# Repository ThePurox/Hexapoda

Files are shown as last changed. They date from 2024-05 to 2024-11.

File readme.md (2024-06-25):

# Hexapoda
The Hexapoda is a [hummingbird](https://github.com/PJE66/hummingbird) style 30 key keyboard designed around [hexagonal keycaps](https://hw.s-ol.nu/HEX-keycaps/), which require Choc v1 switches.
It uses the CH552T controller and [FAK firmware](https://github.com/semickolon/fak).
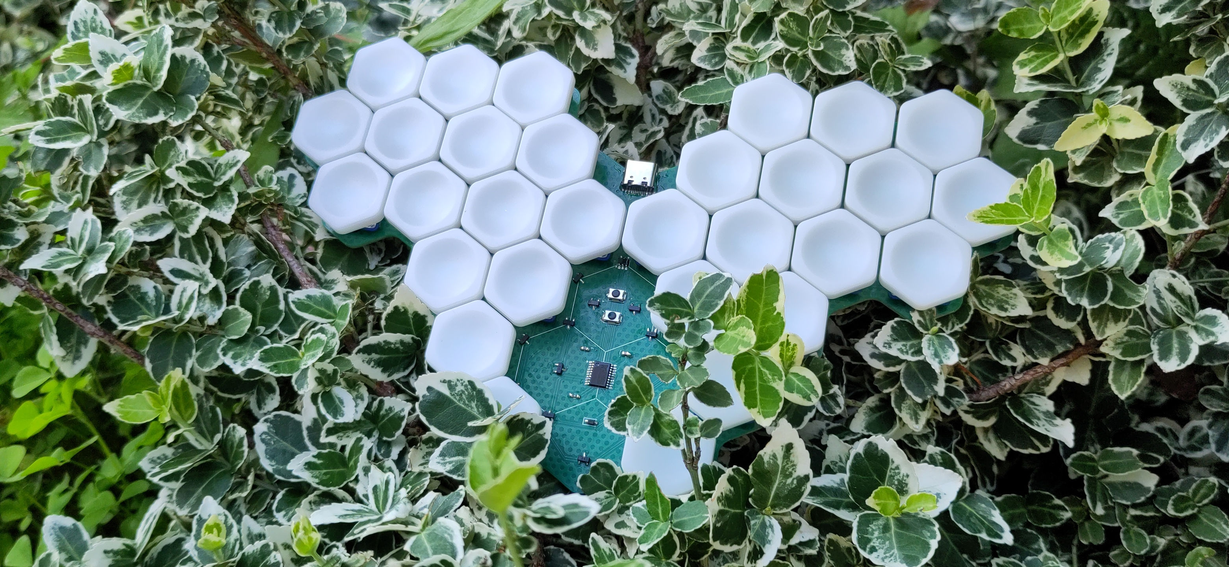
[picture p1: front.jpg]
front view of keyboard

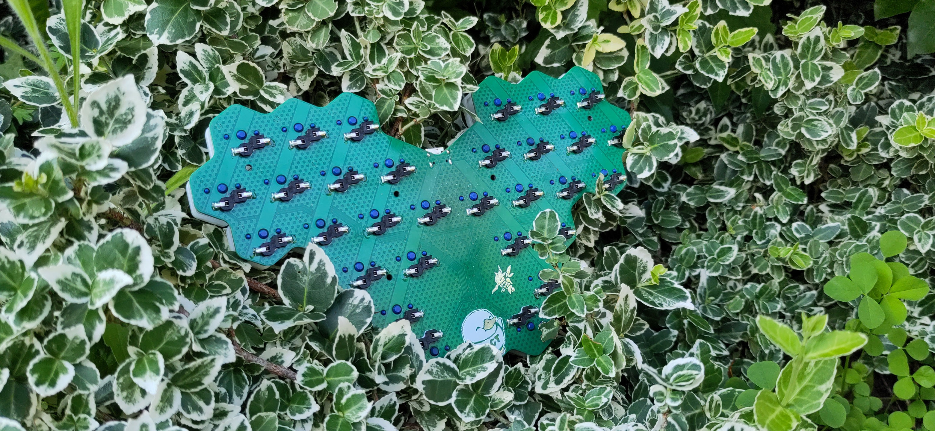
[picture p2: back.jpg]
back view of keyboard


The electronic design is inspired by the [MIAO MCU board](https://github.com/kilipan/miao).

# Buildguide
Soldering should be straight forward with the help of the [interactive bill of materials](bom/ibom.html)
The orientation of `U1` and `U2` are indicated by small arrows on the PCB.
The orientaion `D16` is such that its white line is on the side where the footprint on the silkscreen also has a white line.
For all other components, the orientation does not matter, or their form-factor allows only one orientation (`D1-D15`).
Make sure to also solder the metal legs on the side, as they will give stability to the jack.
Do **not** plug in a USB-cabel without soldering the metal legs on the side of the USB-jack! You will most likely rip off the USB-jack when unplugging the USB-cable!

# Flashing firmware
This keyboard is designed for the [FAK-firmware](https://github.com/semickolon/fak).
I've provided some example configuration files in [my fork](https://github.com/ThePurox/fak-config) of the fak-config repository with the keyboard name `hexapoda`.
The push-button closer to the USB-jack is the `BOOT` button. The one closer to the thumb keys is the `RESET` button.

# BOM
| Part | LCSC-Part Nr | amount |
|---|---|---|
| USB-C | C2765186 | 1 |
| CH552T | C111367 | 1 |
| BAV70 Diodes | C727123 | 15 |
| USBLC6-2SC6 | C6807798 | 1 |
| PMEG2010EA | C193668 | 1 |
| Push buttons | C115357 | 2 |
| Fuse | C311055 | 1 |
| 5.1k-Resistor | C23186 | 2 |
| 10k-Resistor | C25804 | 1 |
| 1uF-Capacitor | C2991434 | 2 |
| Hot-Swap-Sockets | | 30 |
| Choc V1 Switches | | 30 |

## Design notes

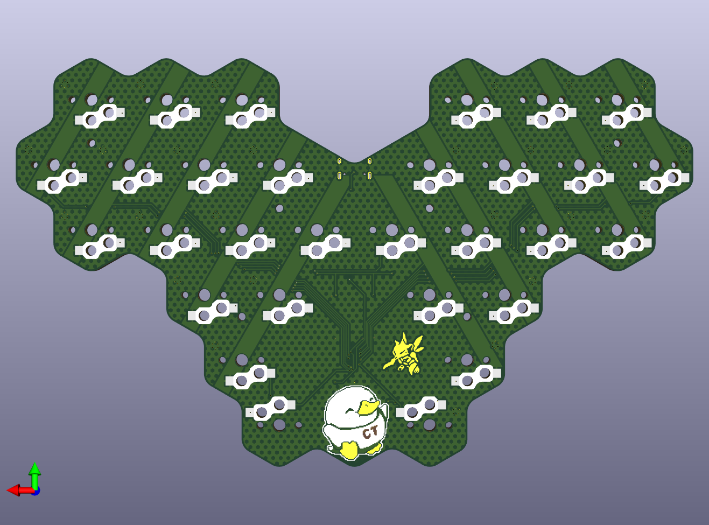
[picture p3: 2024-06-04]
back-pcb.png

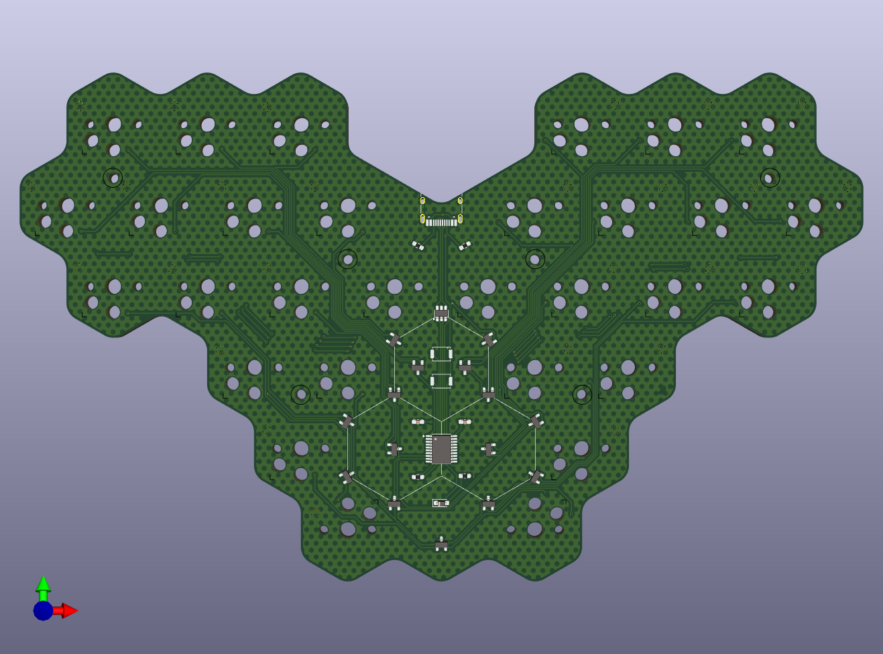
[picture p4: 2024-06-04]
front-pcb.png

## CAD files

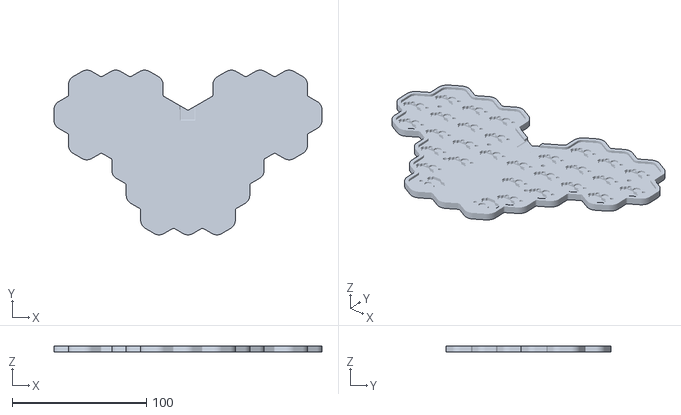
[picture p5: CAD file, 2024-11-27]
case/case.stl
199.5 x 122.6 x 4.40

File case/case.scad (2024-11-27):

$fn=20;

//hotswap
cyl_h=3.05;
cyl_d=3;

base_x=4.75;
base_x_sum=9.55;
base_y=4.65;
base_y_sum=6.85;
base_z=1.8;

clip_x=1.68;
clip_y=(13.15-9.95)/2;
clip_z=1.85;

// based on https://keycapsss.com/media/image/12/7a/49/kailh-choc-switch-low-profile-dimensions.png
// and on https://www.kailhswitch.com/Content/upload/2019306614/201911041105555019799.jpg
module choc_hs(){
    base_x = 4.75;
    base_y = 4.69;
    base_z=1.86;
    clip_x = 1.6;
    clip_y = 1.73;
    pin_h = 2.65;
    minkowski(){
        cylinder(h=0.8,d=1.5);
    rotate([180,0,0])translate([-9.75+base_x/2,-6.9+base_y/2,0]) // center around corner
    union(){
    translate([-base_x/2,-base_y/2,0]) // center around pin hole
    union(){ // HS
    cube([base_x,base_y,base_z]);
    translate([5,2.2,0])cube([base_x,base_y,base_z]);
    translate([base_x,0,0])rotate([0,0,45])cube([base_x+0.30,base_y,base_z]);

    translate([-clip_x,base_y/2-clip_y/2,0])cube([clip_x,clip_y,base_z]);    //clips
    translate([5+base_x,base_y/2-clip_y/2+2.2,0])cube([clip_x,clip_y,base_z]);
    }
    translate([5,-3.8,0]){ // Pins and LED
        cylinder(h=pin_h-pcb_z,d=3.2);
        translate([5.5,0,0])cylinder(h=pin_h-pcb_z,r=0.4);
        translate([-5.5,0,0])cylinder(h=pin_h-pcb_z,r=0.4);
   //     translate([0,-4.7,0.6])cube([7.5,2.2,1.2],center=true);
    }
    }
}
}

first_x = 145.3;
first_y = -31.65;
first_z = -0.0;


hex_x = 21.5;
hex_y = 18.62;
pcb_z = 1.6;
case_z = 2.8;


difference(){
    color("red")translate([0,-130,-case_z])linear_extrude(case_z+pcb_z)offset(r=3)import("butterfly-Edge_Cuts.svg");

color("blue")translate([0,-130,-0.])linear_extrude(pcb_z)offset(0.5)import("butterfly-Edge_Cuts.svg")
    translate([9.75-base_x/2-5,0,0])translate([3.5*hex_x+first_x-5,-1*hex_y+10+first_y,1.5])minkowski(){cube([10,10,2],center=true);sphere(1);} //mcu


translate([first_x,first_y,first_z]){
for(i=[0:2]){
    translate([+i*hex_x,0,0])choc_hs();
    translate([(i+5)*hex_x,0,0])choc_hs();
    }
for(i = [0:3]){
    translate([(i-0.5)*hex_x,-hex_y,0])choc_hs();
    translate([(i)*hex_x,-2*hex_y,0])choc_hs();
}
for(i = [5:8]){
    translate([+(i-0.5)*hex_x,-hex_y,0])choc_hs();
    translate([+(i-1)*hex_x,-2*hex_y,0])choc_hs();
}
translate([+1.5*hex_x,-3*hex_y,0])choc_hs();
translate([+2.5*hex_x,-3*hex_y,0])choc_hs();
translate([+4.5*hex_x,-3*hex_y,0])choc_hs();
translate([+5.5*hex_x,-3*hex_y,0])choc_hs();
translate([+2*hex_x,-4*hex_y,0])choc_hs();
translate([+5*hex_x,-4*hex_y,0])choc_hs();
translate([+2.5*hex_x,-5*hex_y,0])translate([-(9.75-base_x/2-5),-(-6.9+base_y/2-3.8),0])rotate([0,0,180])translate([9.75-base_x/2-5,-6.9+base_y/2-3.8,0])choc_hs();
translate([+4.5*hex_x,-5*hex_y,0])translate([-(9.75-base_x/2-5),-(-6.9+base_y/2-3.8),0])rotate([0,0,180])translate([9.75-base_x/2-5,-6.9+base_y/2-3.8,0])choc_hs();
}
//drill_z = -2.19;

translate([drill_x,drill_y,drill_z]){
    cylinder(h=drill_h,r=drill_r);
    translate([2.5*hex_x,-1*hex_y,0])cylinder(h=drill_h,r=drill_r);
    translate([+4.5*hex_x,-1*hex_y,0])cylinder(h=drill_h,r=drill_r);
    translate([+2*hex_x,-2.5*hex_y-3,0])cylinder(h=drill_h,r=drill_r);
    translate([+5*hex_x,-2.5*hex_y-3,0])cylinder(h=drill_h,r=drill_r);
    translate([+7*hex_x,0,0])cylinder(h=drill_h,r=drill_r);
}

// bumbers
    bumper_h=0.5;
    bumper_d=8.5;
    marker_h=0;
    translate([-(9.75-base_x/2-5),-(-6.9+base_y/2-3.8),-case_z])translate([first_x,first_y,first_z]){
        top_shift=[0,7,0];
        corner_x=5;
        corner_y=5;
        corner_shift_r=[corner_x,corner_y,0];
        corner_shift_l=[-corner_x,corner_y,0];
        bumper_shift=5.5;
        translate(top_shift)bumper(h=bumper_h,d=bumper_d,num=1,ht=marker_h);
        translate([7*hex_x,0,0]+top_shift)bumper(h=bumper_h,d=bumper_d,num=1,ht=marker_h);
        translate([2.5*hex_x,-5*hex_y,0]-corner_shift_r)bumper(h=bumper_h,d=bumper_d,num=1,ht=marker_h);
        translate([4.5*hex_x,-5*hex_y,0]-corner_shift_l)bumper(h=bumper_h,d=bumper_d,num=1,ht=marker_h);

        translate([-0.5*hex_x,-1*hex_y,0]+corner_shift_l)bumper(h=bumper_h,d=bumper_d,num=2,ht=marker_h);
        translate([7.5*hex_x,-1*hex_y,0]+corner_shift_r)bumper(h=bumper_h,d=bumper_d,num=2,ht=marker_h);

        translate([2*hex_x,0,0]+top_shift)bumper(h=bumper_h,d=bumper_d,num=3,ht=marker_h);
        translate([5*hex_x,0,0]+top_shift)bumper(h=bumper_h,d=bumper_d,num=3,ht=marker_h);

     //   translate([2*hex_x,-2*hex_y,0])bumper(h=bumper_h,d=bumper_d,num=4,ht=marker_h);
      //  translate([5*hex_x,-2*hex_y,0])bumper(h=bumper_h,d=bumper_d,num=4,ht=marker_h);

    }
}
drill_x = 142.9;
drill_y = -35.8;
drill_z = -2.19;
drill_r = 1.4;
drill_h = 2.2;

translate([drill_x,drill_y,drill_z]){


    }


module bumper(h, d, num, ht=0.4){
    sq2 = sqrt(2)*d/2;
    difference(){
    cylinder(h=h,d=d);
    translate([0,0,h])
    color("blue"){
    if(num==1){
        translate([0,0,ht/2])scale([0.8,0.8,1])cube([sq2,sq2,ht],center=true);
        }
     if(num==2){
        translate([-sq2/4,0,ht/2])scale([0.8,0.8,1])cube([sq2/2,sq2,ht],center=true);
        translate([sq2/4,0,ht/2])scale([0.8,0.8,1])cube([sq2/2,sq2,ht],center=true);
         }
     if(num==3){
          for(i=[-1:1])translate([i*sq2/(num),0,ht/2])scale([0.8,0.8,1])cube([sq2/3,sq2,ht],center=true);
         }
     if(num==4){
         for(i=[-1:2:1]) for(j=[-1:2:1])
        translate([i*sq2/4,j*sq2/4,ht/2])scale([0.8,0.8,1])cube([sq2/2,sq2/2,ht],center=true);
         }
     }
 }

}

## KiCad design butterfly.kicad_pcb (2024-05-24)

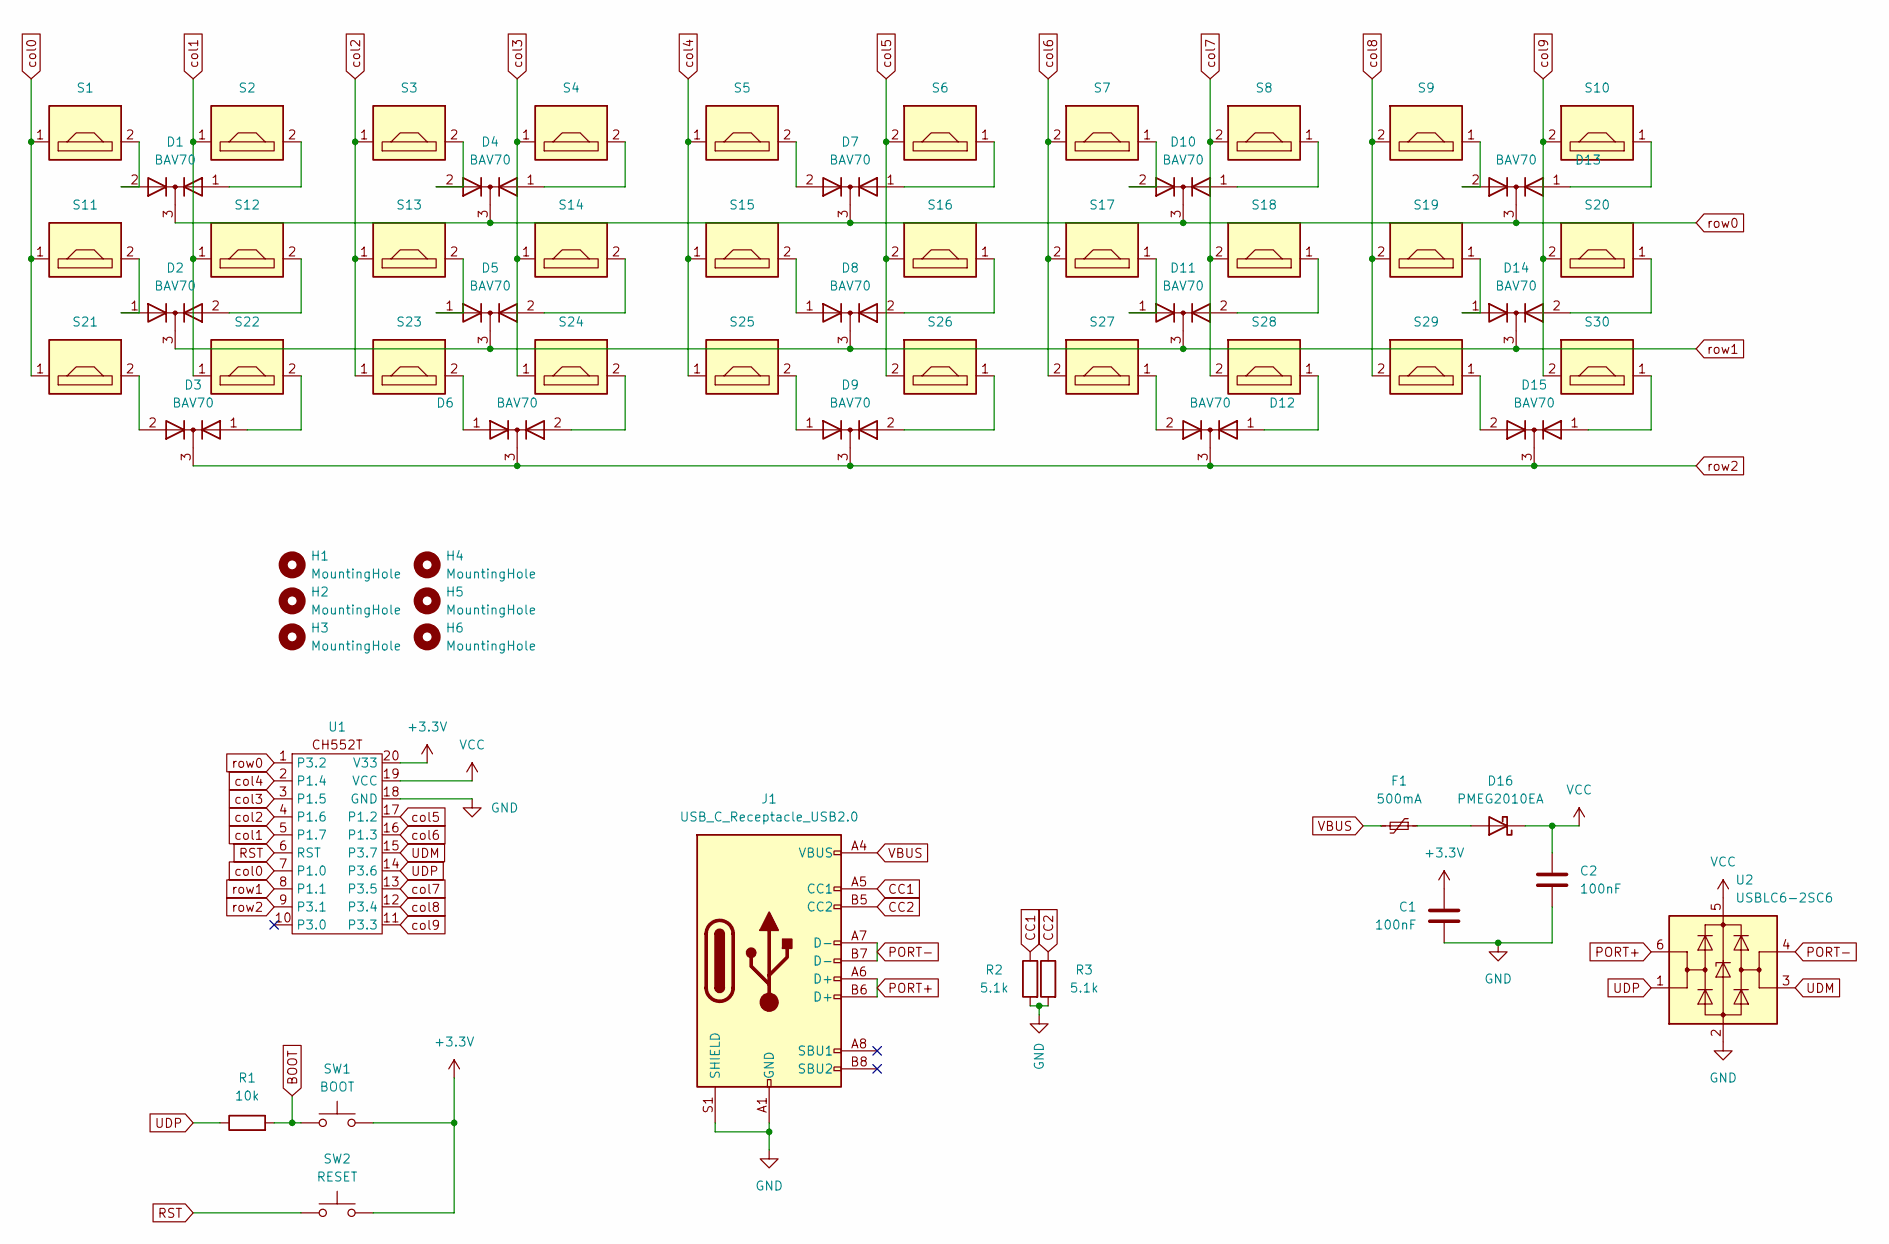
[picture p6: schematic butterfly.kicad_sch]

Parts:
C1, C2: 100nF; C_0603_1608Metric_Pad1.08x0.95mm_HandSolder
D1, D2, D3, D4, D5, D6, D7, D8, D9, D10, D11, D12, D13, D14, D15: BAV70; SOT-23
D16: PMEG2010EA; D_SOD-323_HandSoldering
F1: 500mA; Fuse_0603_1608Metric_Pad1.05x0.95mm_HandSolder
H1, H2, H3, H4, H5, H6: MountingHole; MountingHole_2.2mm_M2
J1: USB_C_Receptacle_USB2.0; USB_C_Receptacle_HRO_TYPE-C-31-M-12
R1: 10k; R_0603_1608Metric_Pad0.98x0.95mm_HandSolder
R2, R3: 5.1k; R_0603_1608Metric_Pad0.98x0.95mm_HandSolder
S1, S2, S3, S4, S5, S6, S7, S8, S9, S10, S11, S12, S13, S14, S15, S16, S17, S18, S19, S20, S21, S22, S23, S24, S25, S26, S27, S28, S29, S30: PG1350; PG1350_hotswap
SW1: BOOT; SW_Push_SPST_NO_Alps_SKRK
SW2: RESET; SW_Push_SPST_NO_Alps_SKRK
U1: TSSOP-20_4.4x6.5mm_P0.65mm
U2: USBLC6-2SC6; SOT-23-6

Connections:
+3.3V: C1.1, SW1.2, SW2.2, U1.20 (V33)
BOOT: R1.2, SW1.1
CC1: J1.A5 (CC1), R2.1
CC2: J1.B5 (CC2), R3.1
GND: C1.2, C2.2, J1.A1 (GND), J1.A12 (GND), J1.B1 (GND), J1.B12 (GND), J1.S1 (SHIELD), R2.2, R3.2, U1.18 (GND), U2.2 (GND)
unnamed: D1.1 (A), S2.2
unnamed: D1.2 (A), S1.2
unnamed: D2.1 (A), S11.2
unnamed: D2.2 (A), S12.2
unnamed: D3.1 (A), S22.2
unnamed: D3.2 (A), S21.2
unnamed: D4.1 (A), S4.2
unnamed: D4.2 (A), S3.2
unnamed: D5.1 (A), S13.2
unnamed: D5.2 (A), S14.2
unnamed: D6.1 (A), S23.2
unnamed: D6.2 (A), S24.2
unnamed: D7.1 (A), S6.1
unnamed: D7.2 (A), S5.2
unnamed: D8.1 (A), S15.2
unnamed: D8.2 (A), S16.1
unnamed: D9.1 (A), S25.2
unnamed: D9.2 (A), S26.1
unnamed: D10.1 (A), S8.1
unnamed: D10.2 (A), S7.1
unnamed: D11.1 (A), S17.1
unnamed: D11.2 (A), S18.1
unnamed: D12.1 (A), S28.1
unnamed: D12.2 (A), S27.1
unnamed: D13.1 (A), S10.1
unnamed: D13.2 (A), S9.1
unnamed: D14.1 (A), S19.1
unnamed: D14.2 (A), S20.1
unnamed: D15.1 (A), S30.1
unnamed: D15.2 (A), S29.1
unnamed: D16.2 (A), F1.1
PORT+: J1.A6 (D+), J1.B6 (D+), U2.6 (I/O1)
PORT-: J1.A7 (D-), J1.B7 (D-), U2.4 (I/O2)
RST: SW2.1, U1.6 (RST)
UDM: U1.15 (P3.7), U2.3 (I/O2)
UDP: R1.1, U1.14 (P3.6), U2.1 (I/O1)
VBUS: F1.2, J1.A4 (VBUS), J1.A9 (VBUS), J1.B4 (VBUS), J1.B9 (VBUS)
VCC: C2.1, D16.1 (K), U1.19 (VCC), U2.5 (VBUS)
col0: S1.1, S11.1, S21.1, U1.7 (P1.0)
col1: S2.1, S12.1, S22.1, U1.5 (P1.7)
col2: S3.1, S13.1, S23.1, U1.4 (P1.6)
col3: S4.1, S14.1, S24.1, U1.3 (P1.5)
col4: S5.1, S15.1, S25.1, U1.2 (P1.4)
col5: S6.2, S16.2, S26.2, U1.17 (P1.2)
col6: S7.2, S17.2, S27.2, U1.16 (P1.3)
col7: S8.2, S18.2, S28.2, U1.13 (P3.5)
col8: S9.2, S19.2, S29.2, U1.12 (P3.4)
col9: S10.2, S20.2, S30.2, U1.11 (P3.3)
row0: D1.3 (K), D4.3 (K), D7.3 (K), D10.3 (K), D13.3 (K), U1.1 (P3.2)
row1: D2.3 (K), D5.3 (K), D8.3 (K), D11.3 (K), D14.3 (K), U1.8 (P1.1)
row2: D3.3 (K), D6.3 (K), D9.3 (K), D12.3 (K), D15.3 (K), U1.9 (P3.1)

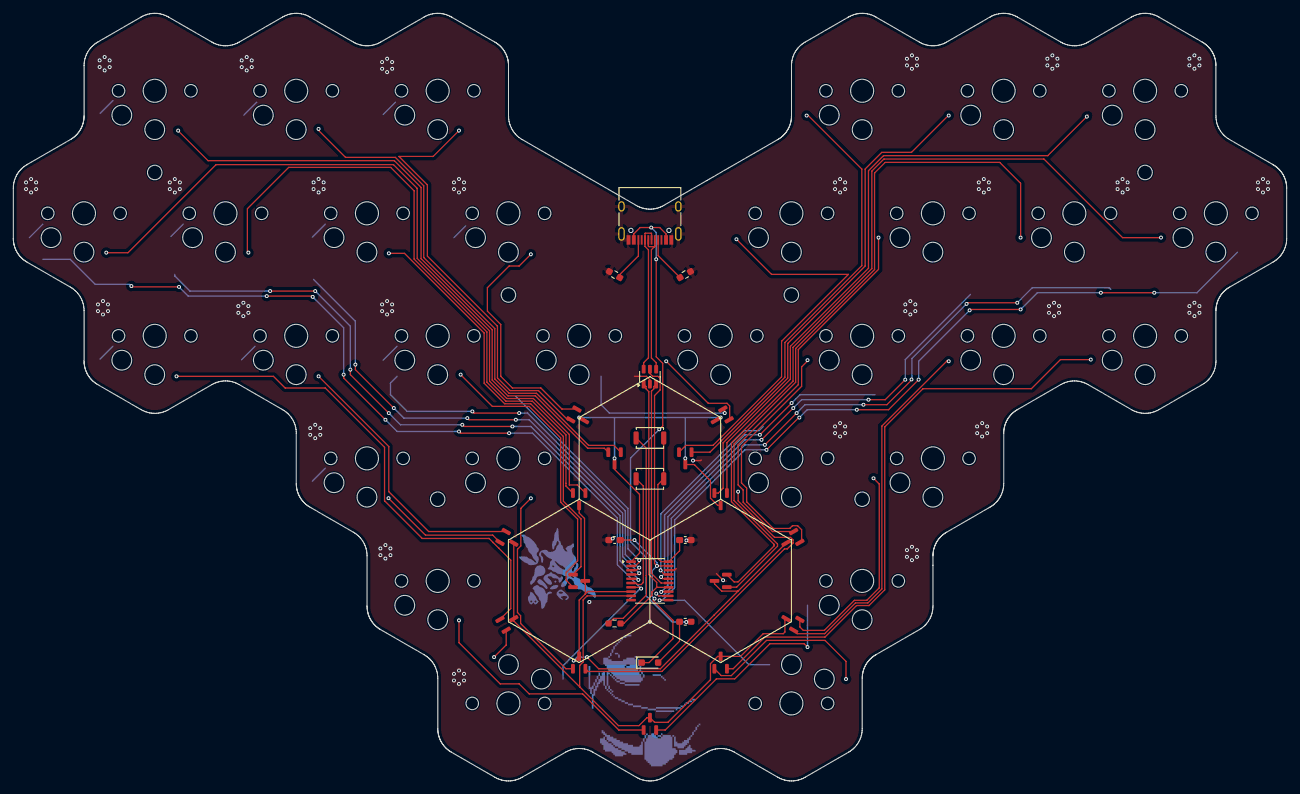
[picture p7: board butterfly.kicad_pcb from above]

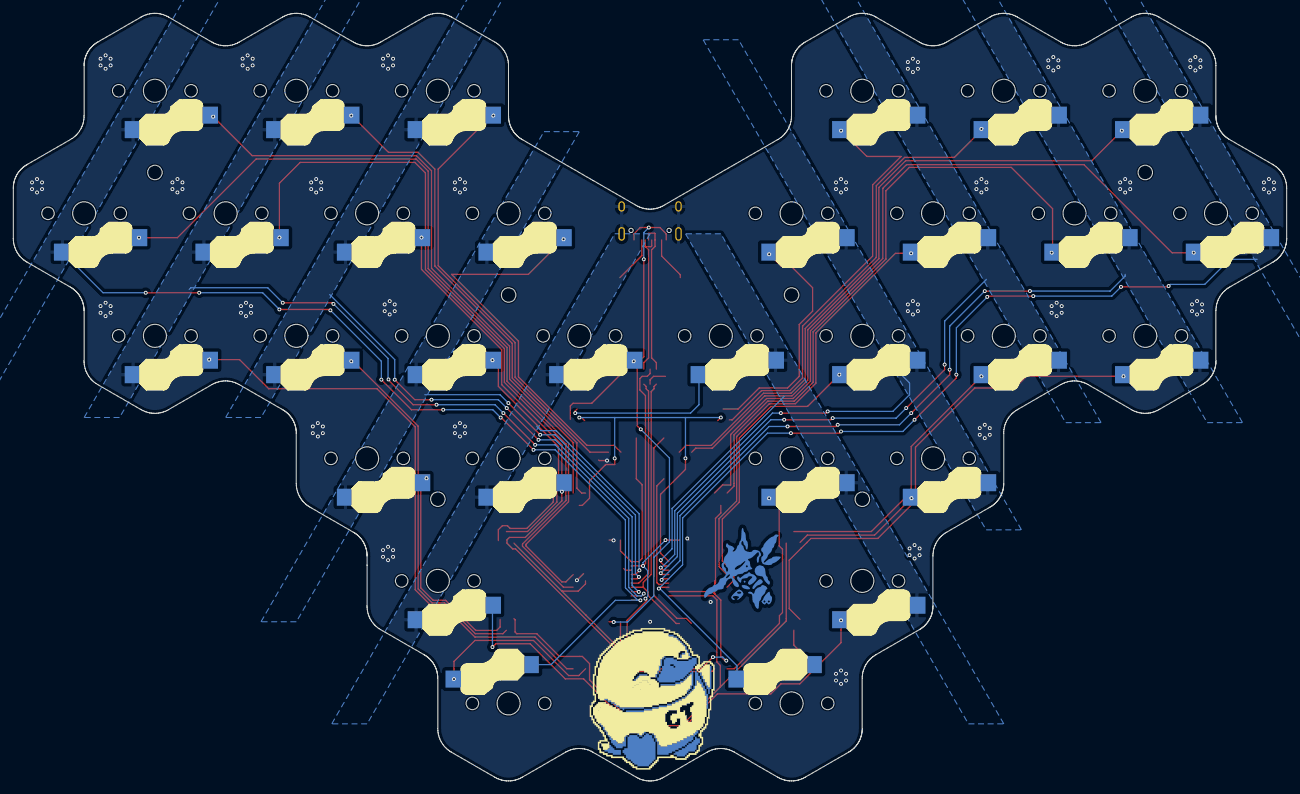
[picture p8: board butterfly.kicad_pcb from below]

Board: 2 copper layers, 193.5 x 116.6 mm, 63 parts (30 on the bottom side), 56 nets.

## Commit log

2024-05-24 before ground-hexing
    [butterfly.kicad_pcb]
2024-06-23 added BOM
2024-06-25 added more explicit warning about soldering the USB-jack mechanically
2024-06-25 added description of buttons
2024-11-27 added case
    [case.scad, case.stl]
